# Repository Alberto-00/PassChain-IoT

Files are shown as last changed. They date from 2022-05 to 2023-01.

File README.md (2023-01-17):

<p align="center">
  
</p>
<p align="center" dir="auto">
   IoT device for password manager. 
  <br>
  A project for IoT Security<br> 
  course at University of Salerno.
</p>

<h1 dir="auto">
  <a id="user-content-project-description-and-introduction" class="anchor" aria-hidden="true" href="#project-description-and-introduction">
    <svg class="octicon octicon-link" viewBox="0 0 16 16" version="1.1" width="16" height="16" aria-hidden="true"><path fill-rule="evenodd" d="M7.775 3.275a.75.75 0 001.06 1.06l1.25-1.25a2 2 0 112.83 2.83l-2.5 2.5a2 2 0 01-2.83 0 .75.75 0 00-1.06 1.06 3.5 3.5 0 004.95 0l2.5-2.5a3.5 3.5 0 00-4.95-4.95l-1.25 1.25zm-4.69 9.64a2 2 0 010-2.83l2.5-2.5a2 2 0 012.83 0 .75.75 0 001.06-1.06 3.5 3.5 0 00-4.95 0l-2.5 2.5a3.5 3.5 0 004.95 4.95l1.25-1.25a.75.75 0 00-1.06-1.06l-1.25 1.25a2 2 0 01-2.83 0z">
      </path>
    </svg>
  </a>
  Project description and introduction
</h1>
<p dir="auto">In this section we introduce context informations for the project.</p>

<h2 dir="auto">
  <a id="user-content-introduction" class="anchor" aria-hidden="true" href="#introduction"><svg class="octicon octicon-link" viewBox="0 0 16 16" version="1.1" width="16" height="16" aria-hidden="true">
    <path fill-rule="evenodd" d="M7.775 3.275a.75.75 0 001.06 1.06l1.25-1.25a2 2 0 112.83 2.83l-2.5 2.5a2 2 0 01-2.83 0 .75.75 0 00-1.06 1.06 3.5 3.5 0 004.95 0l2.5-2.5a3.5 3.5 0 00-4.95-4.95l-1.25 1.25zm-4.69 9.64a2 2 0 010-2.83l2.5-2.5a2 2 0 012.83 0 .75.75 0 001.06-1.06 3.5 3.5 0 00-4.95 0l-2.5 2.5a3.5 3.5 0 004.95 4.95l1.25-1.25a.75.75 0 00-1.06-1.06l-1.25 1.25a2 2 0 01-2.83 0z">
    </path>
    </svg>
  </a>
  Introduction
</h2>
<p dir="auto">
    PassChain is an IoT device to store user's credentials (like username and password) and send them to other devices with a Bluetooth connection. Datas are encrypted with AES-128 bit in GCM mode and the board setup is made connecting PassChain to a server Python with a SSL communication. Each operation is authorized only if the user authenticates himself with a fingerprint.
<br>The project is produced for the IoT Security course of Master's Degree in Cybersecurity at University of Salerno.
</p>

<h1 dir="auto">
  <a id="user-content-technical-informations" class="anchor" aria-hidden="true" href="#technical-informations">
    <svg class="octicon octicon-link" viewBox="0 0 16 16" version="1.1" width="16" height="16" aria-hidden="true">
      <path fill-rule="evenodd" d="M7.775 3.275a.75.75 0 001.06 1.06l1.25-1.25a2 2 0 112.83 2.83l-2.5 2.5a2 2 0 01-2.83 0 .75.75 0 00-1.06 1.06 3.5 3.5 0 004.95 0l2.5-2.5a3.5 3.5 0 00-4.95-4.95l-1.25 1.25zm-4.69 9.64a2 2 0 010-2.83l2.5-2.5a2 2 0 012.83 0 .75.75 0 001.06-1.06 3.5 3.5 0 00-4.95 0l-2.5 2.5a3.5 3.5 0 004.95 4.95l1.25-1.25a.75.75 0 00-1.06-1.06l-1.25 1.25a2 2 0 01-2.83 0z">
      </path>
    </svg>
  </a>
  Technical informations
</h1>
<p dir="auto">In this section we introduce technical informations and installing guides!</p>

<h2 dir="auto">
  <a id="user-content-built-with" class="anchor" aria-hidden="true" href="#hardware"><svg class="octicon octicon-link" viewBox="0 0 16 16" version="1.1" width="16" height="16" aria-hidden="true">
    <path fill-rule="evenodd" d="M7.775 3.275a.75.75 0 001.06 1.06l1.25-1.25a2 2 0 112.83 2.83l-2.5 2.5a2 2 0 01-2.83 0 .75.75 0 00-1.06 1.06 3.5 3.5 0 004.95 0l2.5-2.5a3.5 3.5 0 00-4.95-4.95l-1.25 1.25zm-4.69 9.64a2 2 0 010-2.83l2.5-2.5a2 2 0 012.83 0 .75.75 0 001.06-1.06 3.5 3.5 0 00-4.95 0l-2.5 2.5a3.5 3.5 0 004.95 4.95l1.25-1.25a.75.75 0 00-1.06-1.06l-1.25 1.25a2 2 0 01-2.83 0z">
    </path>
    </svg>
  </a>
  Hardware
  </h2>
<p dir="auto">In this section we can see the circuit, in particular, how all the sensors have been connected to the Esp32 and board's datasheet.</p>
<ul dir="auto">
<li><strong>GPIO 15</strong>: metal plaque to wake up the device when it goes in deep sleep after a constant time;</li>
<li><strong>GPIO 12</strong>: battery circuit is composed of two resistence of 47K, because the board has a voltage between 2.3V - 3.6V. The line red and black are connected to the back of the board: here there is a connector that connect battery to the board;</li><br>
<li><strong>G</strong>: connection with GND (black line);</li>
<li><strong>Red line</strong>: connection with 3V;</li>
<li><strong>GPIO 26</strong>: is TX on the board (RX on fingerprint);</li>
<li><strong>GPIO 27</strong>: is RX on the board (TX on fingerprint);</li>
</ul>
<p>The blue and white line of the fingerprint are used to connect it to serial adapter but in this case we don’t need to use them.</p>
<p dir="auto"> 
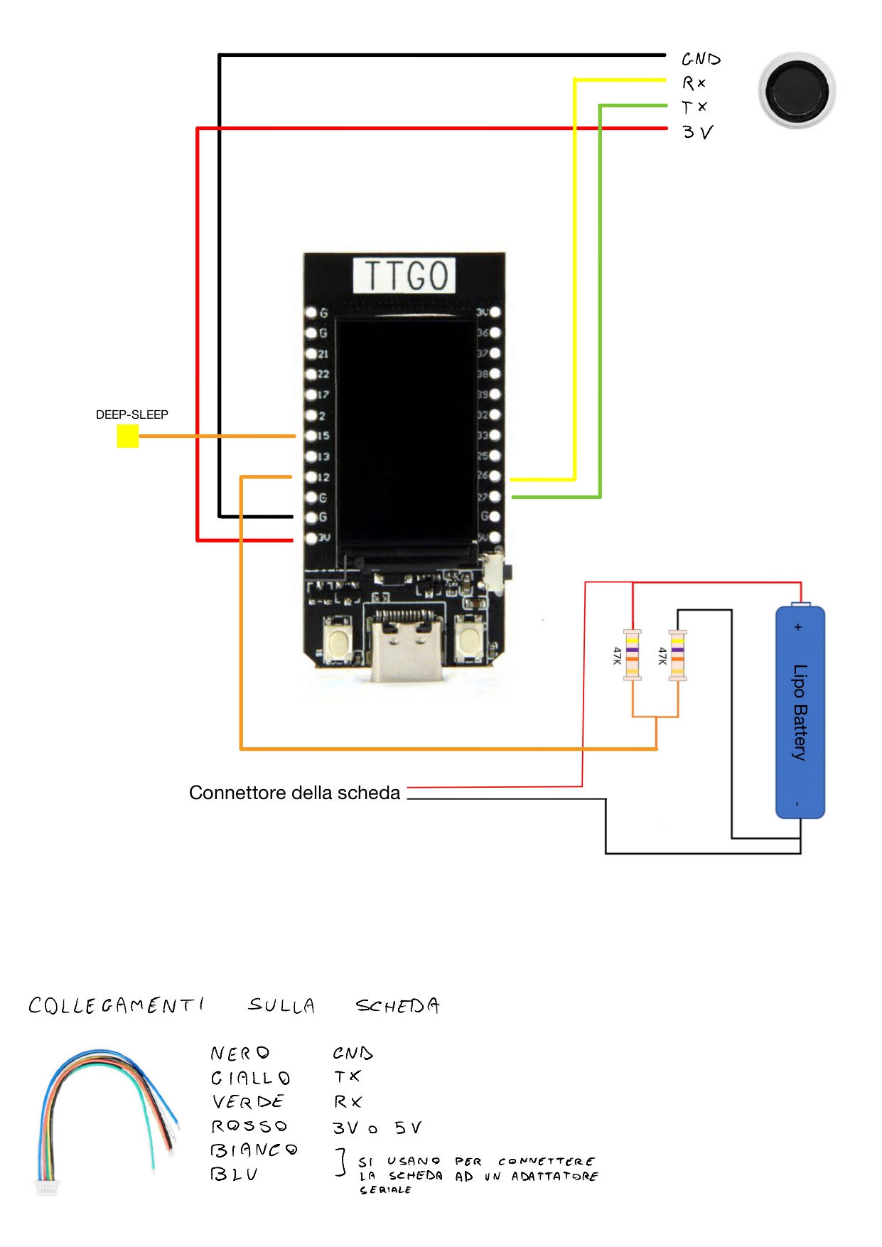
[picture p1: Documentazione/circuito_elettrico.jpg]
  
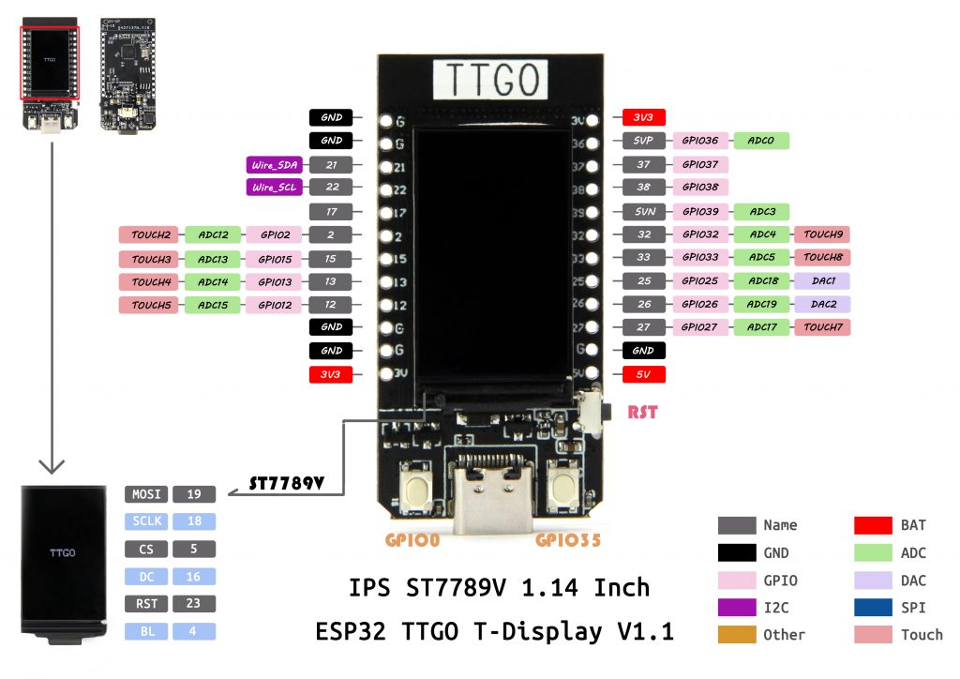
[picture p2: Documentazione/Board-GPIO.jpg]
  
</p>

<h2 dir="auto">
  <a id="user-content-built-with" class="anchor" aria-hidden="true" href="#getting-started"><svg class="octicon octicon-link" viewBox="0 0 16 16" version="1.1" width="16" height="16" aria-hidden="true">
    <path fill-rule="evenodd" d="M7.775 3.275a.75.75 0 001.06 1.06l1.25-1.25a2 2 0 112.83 2.83l-2.5 2.5a2 2 0 01-2.83 0 .75.75 0 00-1.06 1.06 3.5 3.5 0 004.95 0l2.5-2.5a3.5 3.5 0 00-4.95-4.95l-1.25 1.25zm-4.69 9.64a2 2 0 010-2.83l2.5-2.5a2 2 0 012.83 0 .75.75 0 001.06-1.06 3.5 3.5 0 00-4.95 0l-2.5 2.5a3.5 3.5 0 004.95 4.95l1.25-1.25a.75.75 0 00-1.06-1.06l-1.25 1.25a2 2 0 01-2.83 0z">
    </path>
    </svg>
  </a>
  Getting Started
  </h2>
<p dir="auto">We can see how the user does a quick login to a website using PassChain and how the board does connect to server with SSL protocol.</p>

<h3 dir="auto"><a id="user-content-first-mode" class="anchor" aria-hidden="true" href="#first-mode"><svg class="octicon octicon-link" viewBox="0 0 16 16" version="1.1" width="16" height="16" aria-hidden="true"><path fill-rule="evenodd" d="M7.775 3.275a.75.75 0 001.06 1.06l1.25-1.25a2 2 0 112.83 2.83l-2.5 2.5a2 2 0 01-2.83 0 .75.75 0 00-1.06 1.06 3.5 3.5 0 004.95 0l2.5-2.5a3.5 3.5 0 00-4.95-4.95l-1.25 1.25zm-4.69 9.64a2 2 0 010-2.83l2.5-2.5a2 2 0 012.83 0 .75.75 0 001.06-1.06 3.5 3.5 0 00-4.95 0l-2.5 2.5a3.5 3.5 0 004.95 4.95l1.25-1.25a.75.75 0 00-1.06-1.06l-1.25 1.25a2 2 0 01-2.83 0z"></path></svg></a>Send Credential</h3>


<h3 dir="auto"><a id="user-content-first-mode" class="anchor" aria-hidden="true" href="#first-mode"><svg class="octicon octicon-link" viewBox="0 0 16 16" version="1.1" width="16" height="16" aria-hidden="true"><path fill-rule="evenodd" d="M7.775 3.275a.75.75 0 001.06 1.06l1.25-1.25a2 2 0 112.83 2.83l-2.5 2.5a2 2 0 01-2.83 0 .75.75 0 00-1.06 1.06 3.5 3.5 0 004.95 0l2.5-2.5a3.5 3.5 0 00-4.95-4.95l-1.25 1.25zm-4.69 9.64a2 2 0 010-2.83l2.5-2.5a2 2 0 012.83 0 .75.75 0 001.06-1.06 3.5 3.5 0 00-4.95 0l-2.5 2.5a3.5 3.5 0 004.95 4.95l1.25-1.25a.75.75 0 00-1.06-1.06l-1.25 1.25a2 2 0 01-2.83 0z"></path></svg></a>Server Python</h3>


<h2 dir="auto">
  <a id="user-content-built-with" class="anchor" aria-hidden="true" href="#built-with"><svg class="octicon octicon-link" viewBox="0 0 16 16" version="1.1" width="16" height="16" aria-hidden="true">
    <path fill-rule="evenodd" d="M7.775 3.275a.75.75 0 001.06 1.06l1.25-1.25a2 2 0 112.83 2.83l-2.5 2.5a2 2 0 01-2.83 0 .75.75 0 00-1.06 1.06 3.5 3.5 0 004.95 0l2.5-2.5a3.5 3.5 0 00-4.95-4.95l-1.25 1.25zm-4.69 9.64a2 2 0 010-2.83l2.5-2.5a2 2 0 012.83 0 .75.75 0 001.06-1.06 3.5 3.5 0 00-4.95 0l-2.5 2.5a3.5 3.5 0 004.95 4.95l1.25-1.25a.75.75 0 00-1.06-1.06l-1.25 1.25a2 2 0 01-2.83 0z">
    </path>
    </svg>
  </a>
  Built With
  </h2>
<ul dir="auto">
  <li><a href="https://www.arduino.cc/en/software" rel="nofollow">Arduino IDE</a> - The programming language used for the board development.</li>
  <li><a href="http://www.lilygo.cn/" rel="nofollow">Lora TTgo Esp32</a> - Board used for the project.</li>
  <li><a href="https://www.adafruit.com/product/751" rel="nofollow">Adafruit Fingerprint</a> - Sensor for user authentication.</li>
  <li><a href="#" rel="nofollow">LiPo battery 500 mAh</a> - Battery of 3.7V.</li>
  <li><a href="https://github.com/Mbed-TLS/mbedtls" rel="nofollow">mbedtls/gcm</a> - Library used to encrypt and decrypt datas with AES-128 bit (GCM mode).</li>
  <li><a href="https://github.com/espressif/arduino-esp32/tree/master/libraries/WiFiClientSecure" rel="nofollow">WiFiClientSecure/gcm</a> - Library used to create and setup SSL communication.</li>
  <li><a href="https://github.com/T-vK/ESP32-BLE-Keyboard" rel="nofollow">BleKeyboard</a> - Library used to simulate a virtual keyboard.</li>
  <li><a href="https://www.openssl.org/" rel="nofollow">Openssl</a> - To generate certificates for SSL communication.</li>
  <li><a href=https://www.python.org/" rel="nofollow">Python</a> - The programming language used for server development.</li>
</ul>

<h2 dir="auto">
  <a id="user-content-authors" class="anchor" aria-hidden="true" href="#authors">
    <svg class="octicon octicon-link" viewBox="0 0 16 16" version="1.1" width="16" height="16" aria-hidden="true"><path fill-rule="evenodd" d="M7.775 3.275a.75.75 0 001.06 1.06l1.25-1.25a2 2 0 112.83 2.83l-2.5 2.5a2 2 0 01-2.83 0 .75.75 0 00-1.06 1.06 3.5 3.5 0 004.95 0l2.5-2.5a3.5 3.5 0 00-4.95-4.95l-1.25 1.25zm-4.69 9.64a2 2 0 010-2.83l2.5-2.5a2 2 0 012.83 0 .75.75 0 001.06-1.06 3.5 3.5 0 00-4.95 0l-2.5 2.5a3.5 3.5 0 004.95 4.95l1.25-1.25a.75.75 0 00-1.06-1.06l-1.25 1.25a2 2 0 01-2.83 0z">
      </path>
    </svg>
  </a>
  Author & Contacts
</h2>
<p dir="auto"><strong>Alberto Montefusco</strong>   - <em>Developer</em>   - <a href="https://github.com/Alberto-00">Alberto-00</a></p>
<p dir="auto">Email - <a href="mailto:a.montefusco28@studenti.unisa.it">a.montefusco28@studenti.unisa.it</a></p>
<p dir="auto">LinkedIn - <a href="https://www.linkedin.com/in/alberto-montefusco">Alberto Montefusco</a></p>
<p dir="auto">My WebSite - <a href="https://alberto-00.github.io/">alberto-00.github.io</a></p>

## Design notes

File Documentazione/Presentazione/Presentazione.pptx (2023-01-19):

## void PassChain_IoT() {

PassChain.ino

Details.ino

/* Presentazione di Alberto Montefusco */

const char *corso = ‘IoT Security’;

}

const char *Prof = ‘Christiancarmine Esposito’;

const char *aa = ‘2022 - 2023’;

Presentation.begin(course, Prof, aa);

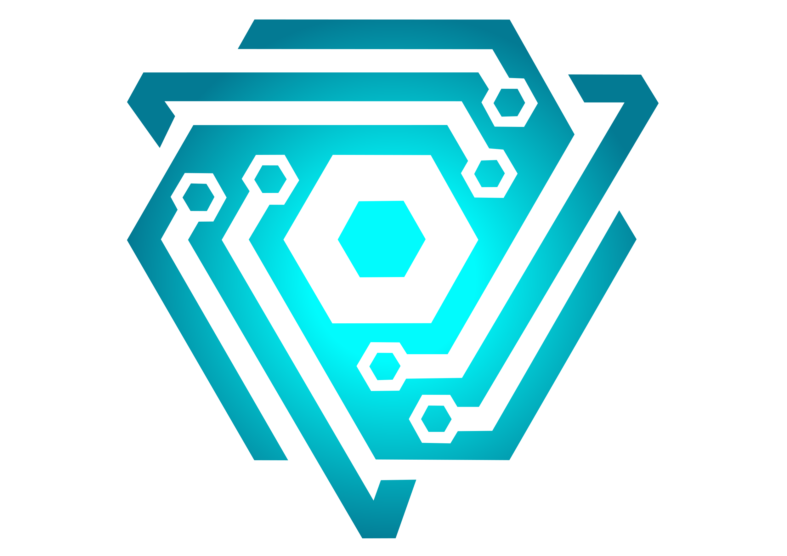
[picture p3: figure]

Arduino Language

## 01 02 03 Table Of ‘Contents’ {

PassChain.ino

Details.ino

}

Introduzione

/* Introduzione ai Password Manager e a PassChain */

Hardware

/* Sensori usati e descrizione del circuito finale */

Software

/* Librerie usate, comunicazione SSL, server Python */

04

Vulnerabilità_&_Sicurezza

/* Attacchi e Soluzioni Sicure */

Arduino Language

## 01 { [Introduzione]

PassChain.ino

Details.ino

/* Cos’è un PassWord Manager
e il dispositivo PassChain */

}

Arduino Language

## Password_Manager {

PassChain.ino

/* Cosa sono? */

Details.ino

}

Serial.println(‘Servizi online che permettono all’utente di salvare password’);
delay(100);

Serial.println(‘ e sincronizzarle su tutti i dispositivi personali’);

Arduino Language

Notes: Permettono, quindi, un’archiviazione sicura e cifrata mediante l’utilizzo di una Master Password, che serve per accedere al password manager.

## tft.pushImage (

PassChain.ino

Details.ino

Dashlane e 1Password sono i Password Manager più famosi

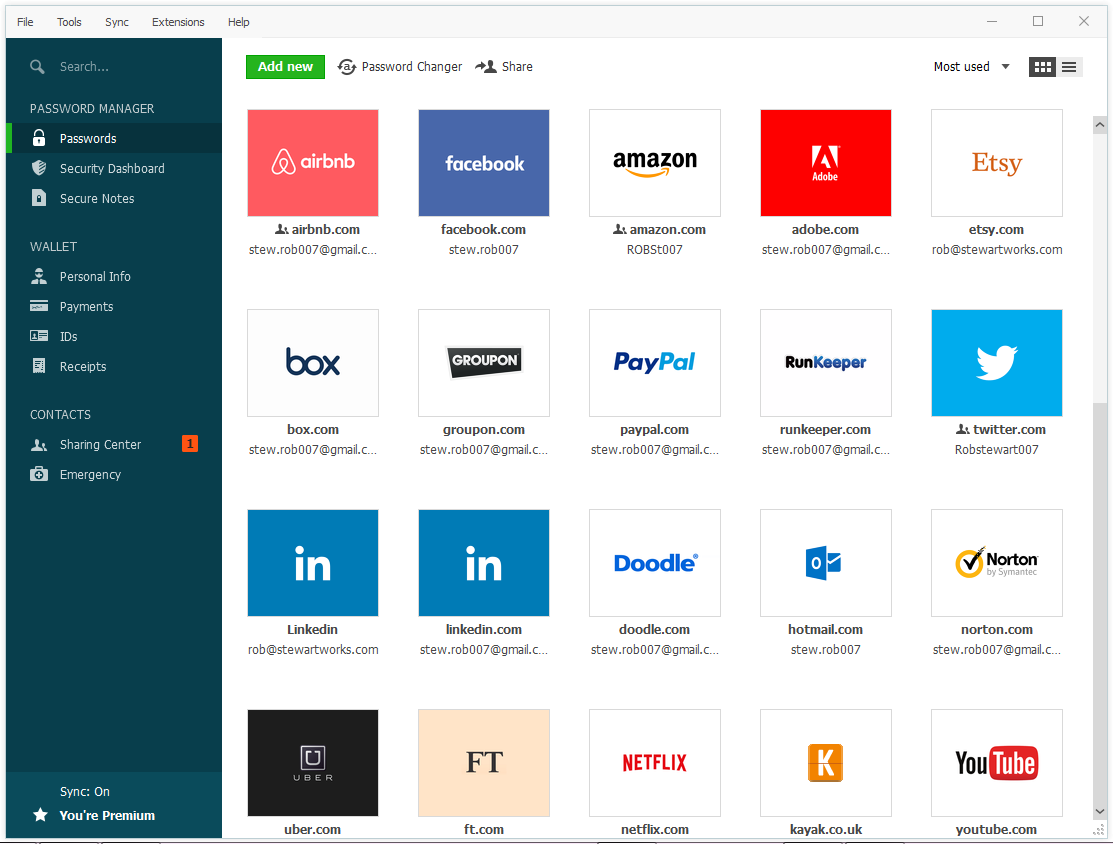
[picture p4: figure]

);

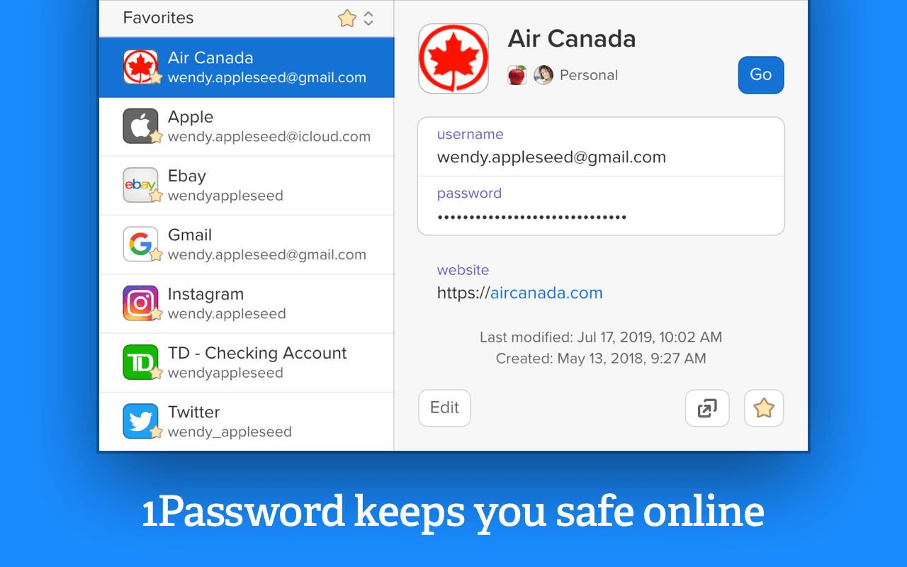
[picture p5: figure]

Arduino Language

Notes: Tra I password manager più famosi abbiamo Dashline e 1Password

## Serial.println (‘Vantaggi: ‘ +

PassChain.ino

Details.ino

Step 01

Le App sono disponibili per tutte le piattaforme

Step 02

Alcune estensioni Browser permettono di inserire le password automaticamente

Step 03

Le password sono sincronizzate su tutti i dispositivi

Step 04

Accesso veloce

);

Arduino Language

## Serial.println (‘Svantaggi: ‘ +

PassChain.ino

Details.ino

Step 01

I servizi online e cloud possono essere violati anche da remoto

Step 02

Installare un'applicazione o un'estensione su ciascuno dei propri dispositivi personali

Step 03

Meno pratico quando si usano dispositivi non personali

Sigle Point of Failure perché l'accesso a tutte le tue password è protetto da un'unica password sicura

Step 04

);

Arduino Language

## PassChain_IoT {

PassChain.ino

/* Cos’è PassChain? */

Serial.println(‘PassChain è un dispositivo IoT con l’obbietivo di facilitare l'utente durante l’autenticazione digitale’);
delay(100);
Serial.println(‘ma anche di garantire la loro sicurezza attraverso la sua funzione di password manager’);

Details.ino

}

Bluetooth

< Connessione ad altri dispositivi tramite Bluetooth >

Autenticazione

< Ogni operazione è compiuta tramite autenticazione con Fingerprint >

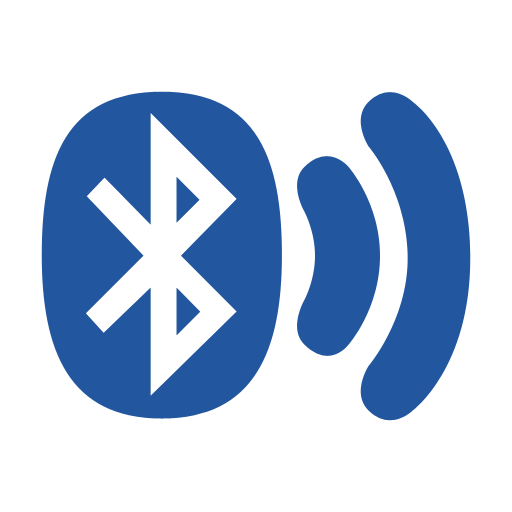
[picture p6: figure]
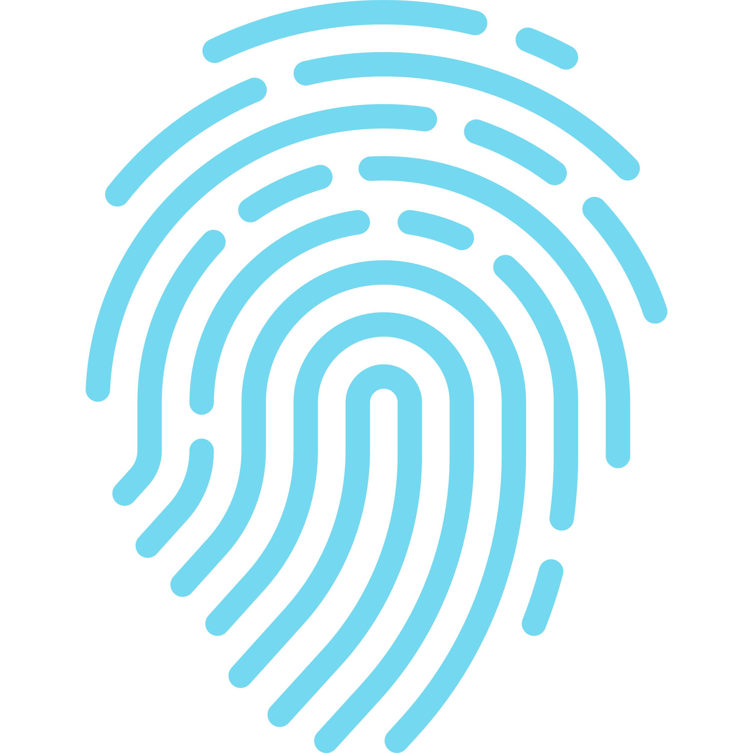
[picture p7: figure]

Crittografia

< Tutti i dati sono cifrati con lo schema AES 128 bit – GCM >

Comunicazione SSL

< SSL garantisce una comunicazione sicura con il server python >

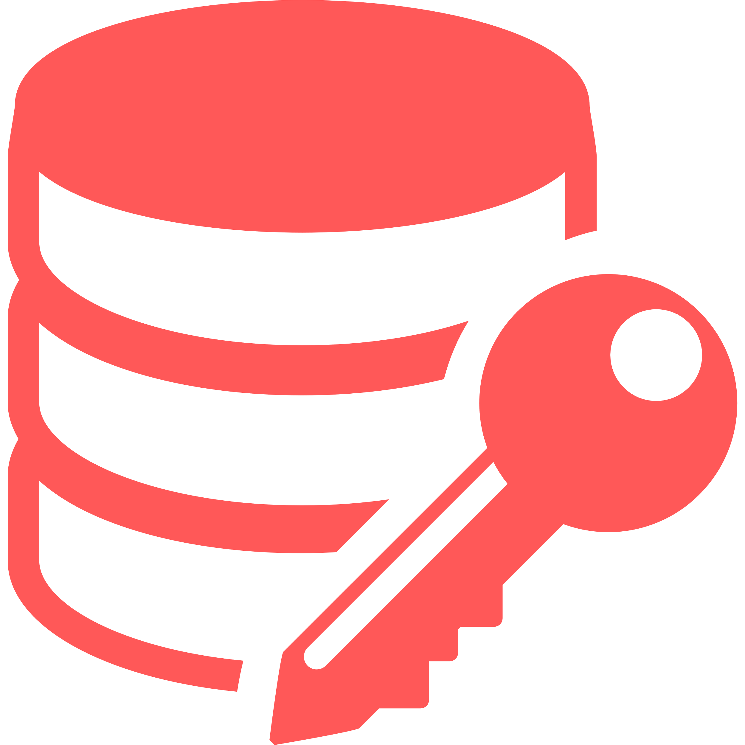
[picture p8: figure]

Arduino Language

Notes: PassChain è un dispositivo IoT con l’obbietivo di facilitare l'utente durante l’autenticazione digitale permettendogli di inviare le credenziali a qualsiasi dispositivo che supporta una connessione Bluetooth. Inoltre, garantisce anche una forte sicurezza grazie alla sua funzione di password manager, infatti, tutti i dati all’interno sono cifrati.

## SD_Send_Credential {

PassChain.ino

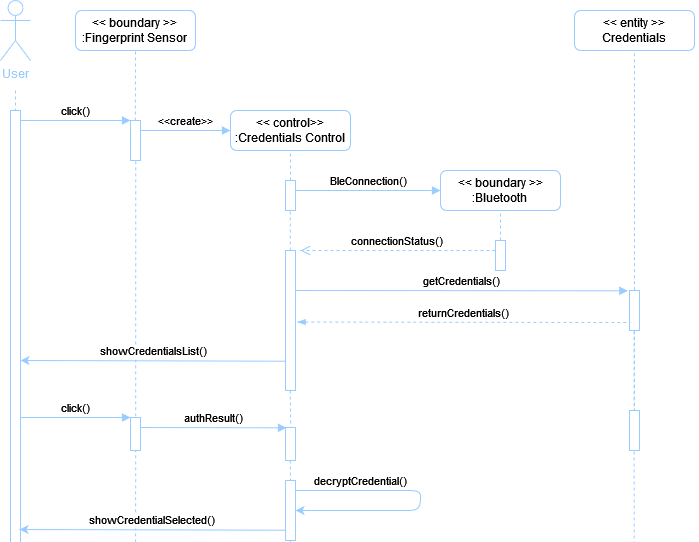
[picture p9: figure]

Arduino Language

Details.ino

}

## SD_Send_Credential {

PassChain.ino

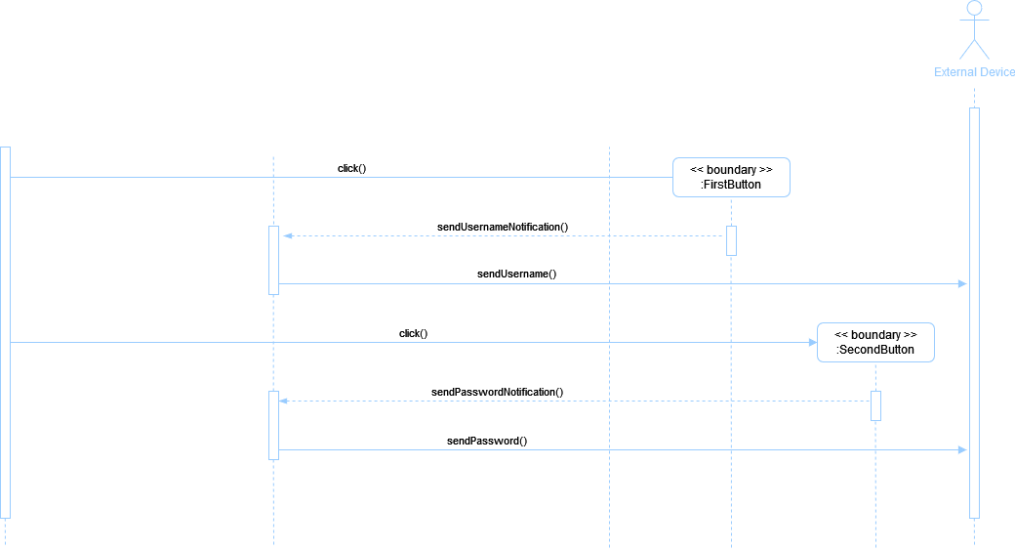
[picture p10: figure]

Details.ino

}

Arduino Language

## SD_Server_Operation {

PassChain.ino

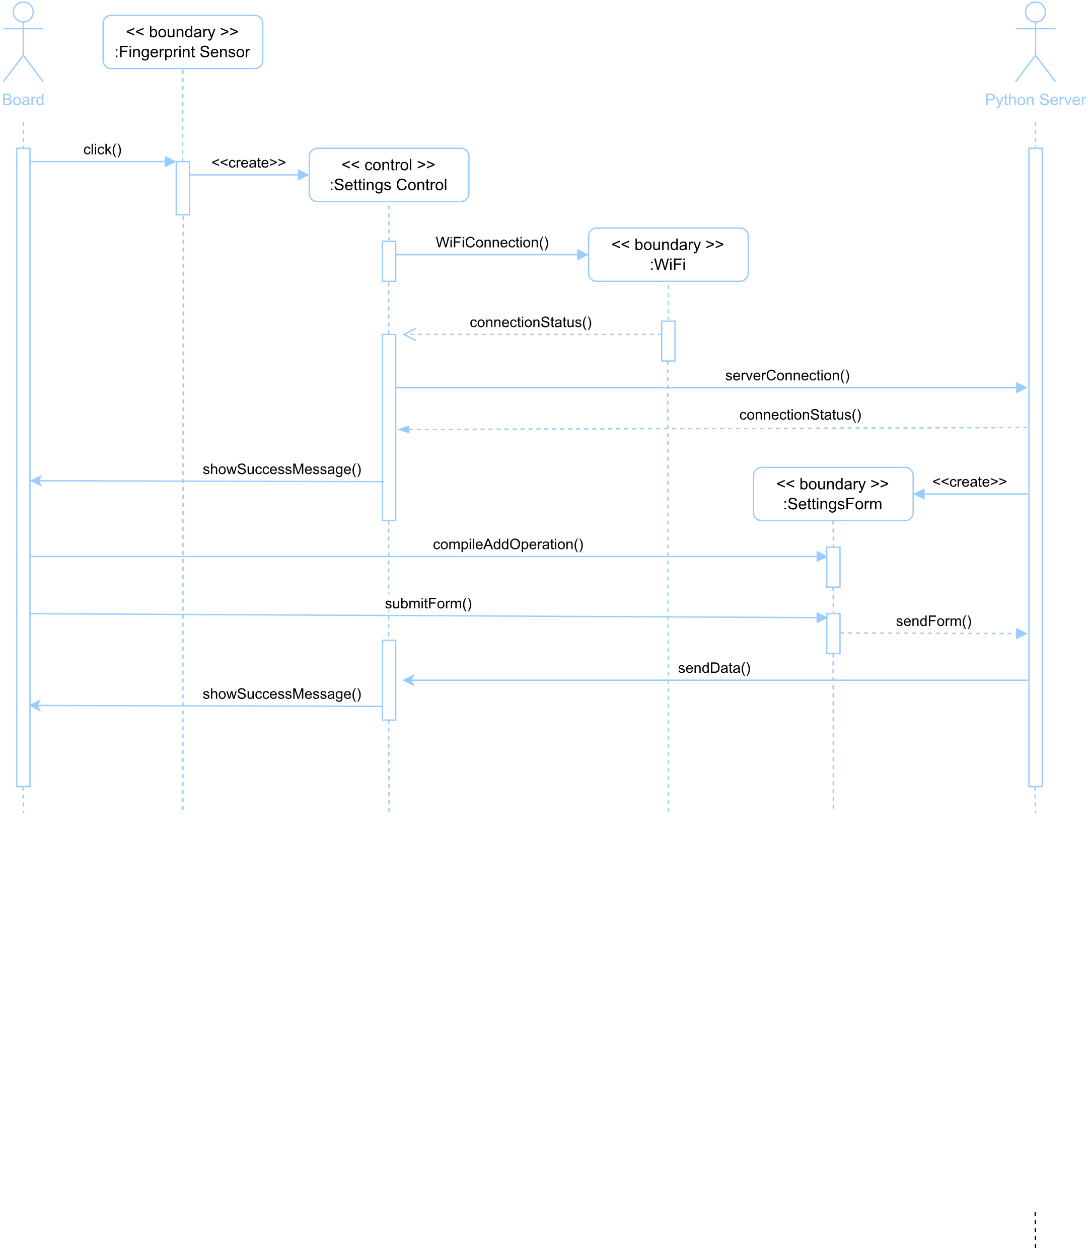
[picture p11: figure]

Arduino Language

Details.ino

}

## 02 { [Hardware]

PassChain.ino

Details.ino

/* Lora TTgo Esp32 16 Mb,
Fingerprint, Battery */

}

Arduino Language

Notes: Now we can see the Hardware used

## void Lora_TTgo_Esp32 () {

PassChain.ino

< La scheda ha un display OLED integrato da 0,96'', due pulsanti programmabili e uno per il riavvio, un connettore di alimentazione per le batterie e una porta di tipo C per il collegamento del dispositivo e l'alimentazione della scheda stessa. Ha una memoria di 16 Mb con SPIFFS come file system >

Details.ino

}

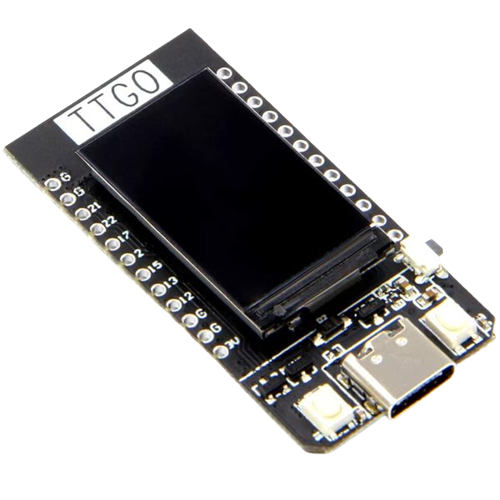
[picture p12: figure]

void Fingerprint () {

< Il sensore di impronte digitali consente di autenticare l'utente garantendone l'unicità. Il sensore può memorizzare 126 impronte digitali: una di queste serve per tornare indietro nelle impostazioni >

}

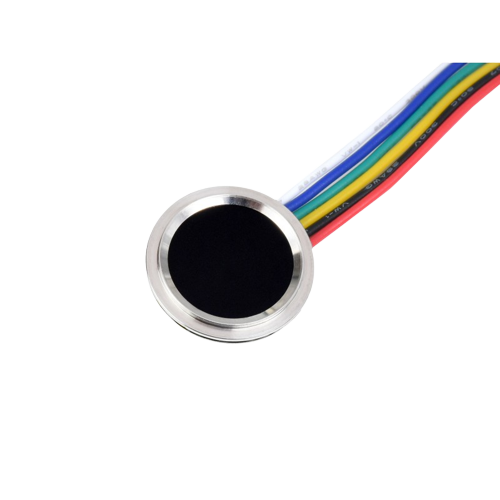
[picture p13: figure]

Arduino Language

## void Lora_Ttgo_Esp32 () {

PassChain.ino

< La batteria LiPo da 500 mAh e 3,7 V consente di avere un dispositivo portatile e indipendente >

Details.ino

}

void show_circuit (Board esp32, Sensor fingerprint, Sensor battery) {

Circuit circuit = new Circuit (Esp32, fingerprint, battery);

}

tft.pushImage(circuit.show());

Arduino Language

## tft.pushImage (

PassChain.ino

Details.ino

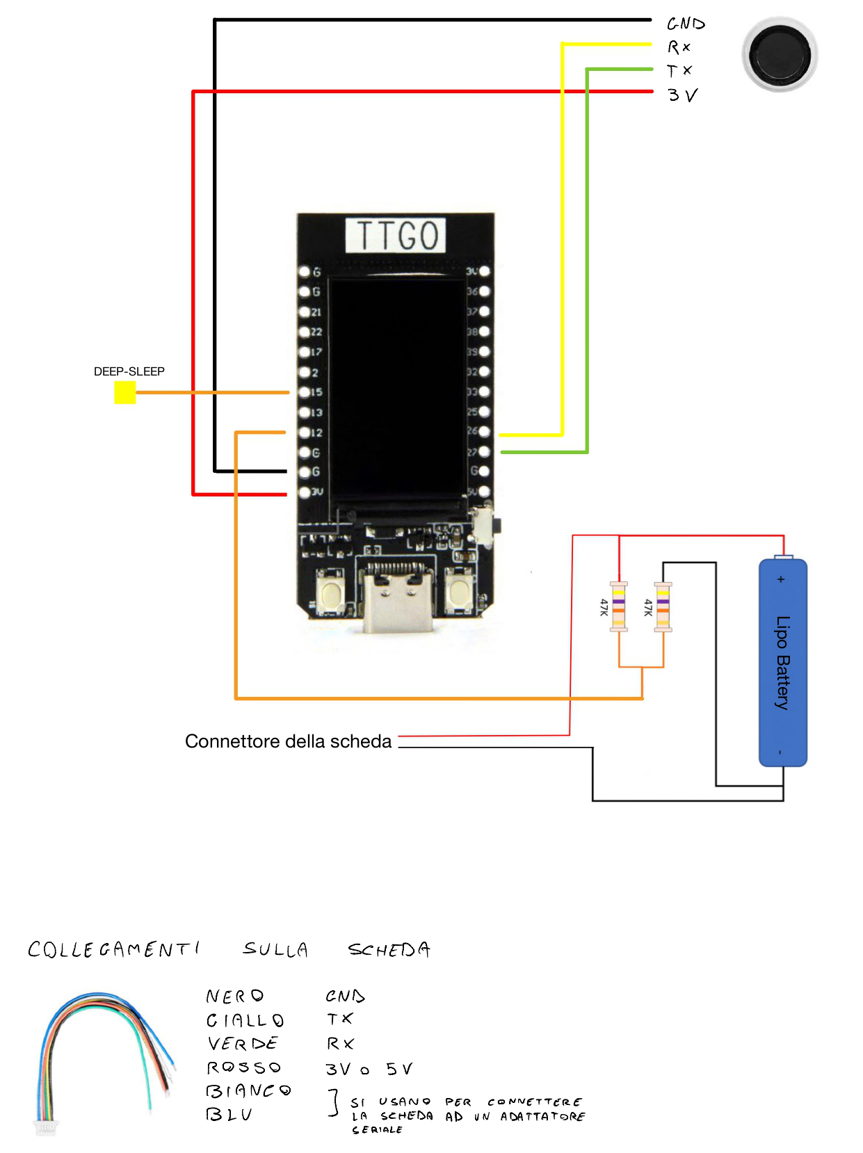
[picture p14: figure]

- GPIO 15: placca metallica per riattivare la board quando entra in modalità deep_sleep
- GPIO 12: circuito della batteria

);

Arduino Language

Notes: Sul GPIO 15 è collegata una placca metallica per riattivare il dispositivo quando entra in modalità deep sleep dopo un certo intervallo di tempo.

Sul GPIO 12 è collegata la batteria, in particolare il circuito è composto da due resistenze da 47K, in quanto la scheda ha una tensione compresa tra 2.3V - 3.6V. Le linee rossa e nera sono collegate al retro della scheda: qui c'è un connettore che collega la batteria alla scheda

## tft.pushImage (

PassChain.ino

Details.ino

- G: connnessione con GND
- La line rossa è collegata alla 3V
- GPIO 26: TX della scheda
- GPIO 27: RX della scheda

);

Arduino Language

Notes: Ora vediamo il collegamento del sensore del fingerprint:
G è la connessione con GND (linea nera);
la linea rossa è la connessione con 3V;
GPIO 26 (linea gialla) è TX sulla scheda (RX sul dito);
GPIO 27 (linea verde) è RX sulla scheda (TX sul dito);
La linea blu e bianca dell'impronta digitale servono per collegarla ad un’adattatore seriale ma in questo caso non vengono utilizzate.

## 03 { [Software]

PassChain.ino

Details.ino

/* Librerie usate, comunicazione SSL,
server Python */

}

Arduino Language

## Libraries_used(bool external) { < TFT_eSPI.h > < SD.h >

PassChain.ino

Details.ino

if (!external) { /* dettagli librerie Arduino */

- Libreria Arduino usata per scrivere
- testo o visualizzare immagini sul
- display OLED.

- Libreria Arduino per leggere e scrivere
- in memoria. Il file system usato è
- SPIFFS.

Libreria Arduino usata per gestire i
file JSON, nei quali sono memorizzate
le credenziali utente e dell’Hotspot

< ArduinoJson.h >

Arduino Language

## < WiFiClientSecure.h > < BleKeyboard.h >

PassChain.ino

< mbedtls/gcm.h >

Details.ino

- Libreria Arduino usata per creare e
- fare il setup della comunicazione SSL

Cifratura e decifratura dei dati con lo
schema AES - 128 bit GCM mode

} else { /* dettagli delle librerie esterne */

- Simulare una tastiera virtuale e
- inviare i messaggi tramite Bluetooth

Gestione delle impronte digitali

}

< Adafruit_Fingerprint.h >

}

Arduino Language

## SSL_Communication {

PassChain.ino

Details.ino

/***********************************************************************
* Ho creato una comunicazione sicura tra l’Esp32 e il dispositivo *
* esterno che funge da server per fare il setup dei dati. *
***********************************************************************/

}

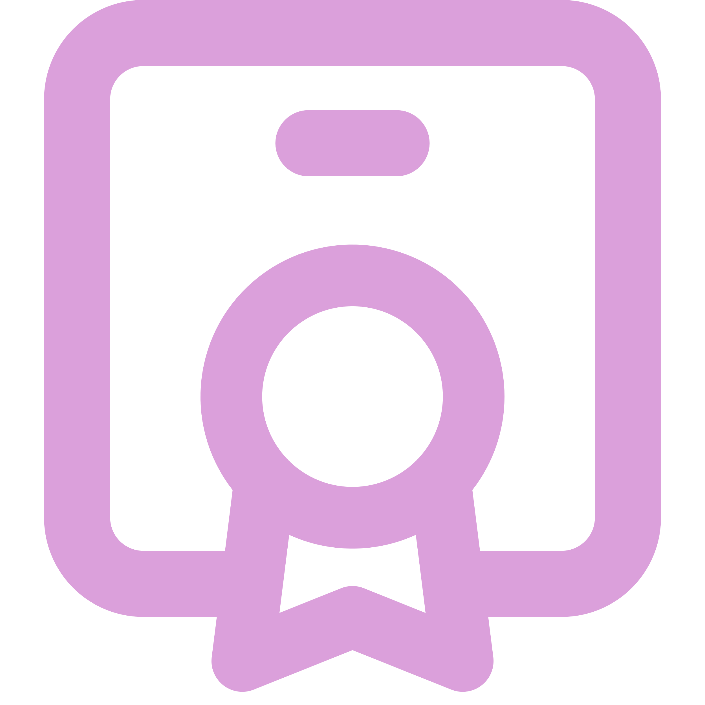
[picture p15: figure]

Creazione Certificati

< Certificati CA, client e chiave associata del client >

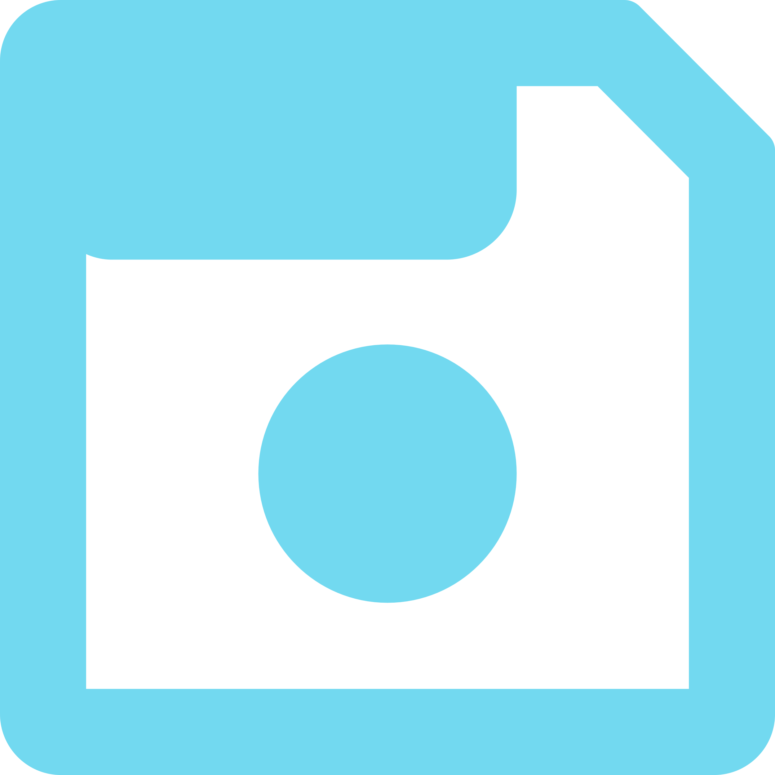
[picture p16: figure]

Salvataggio Certificati

< I certificati sono salvati nel codice Arduino e inviati al server >

Start Server Python

< Caricamento del certificato del server e verifica di esso e del certificato client >

Recezione dati

< Il server crea una socket e riceve i dati dall’ESP32 >

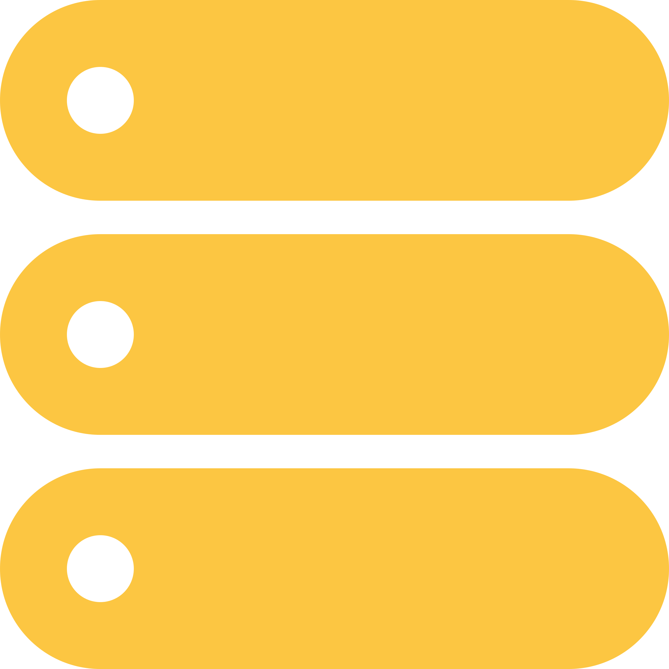
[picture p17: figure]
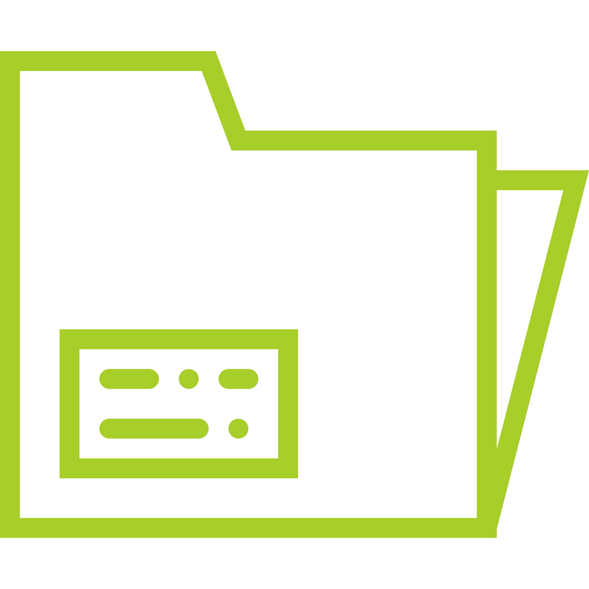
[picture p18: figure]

Arduino Language

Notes: La comunicazione SSL consente una comunicazione sicura tra due dispositivi. In questo caso, creo una comunicazione sicura tra l’Esp32 e il dispositivo esterno che funge da server per fare il setup dei dati.

I primi passi sono la creazione dei certificati CA, client e server con le relative chiavi (io ho usato openssl, in particolare rsa 2048 bit);
Il secondo passo è memorizzare il CA, client e la sua chiave nel codice Arduino e quindi inviare il certificato client al server per verificarlo.
Il server python carica il certificato del server e lo verifica.
Il server crea una socket su una porta specifica e si prepara a ricevere dati da Esp32.

## Server_Python {

PassChain.ino

Details.ino

/***********************************************************************
* Permette di effettuare il setup della scheda. Le operazioni *
* riguardano: aggiunta, modifica ed eliminazione delle credenziali, *
* setup del fingerprint, setup credenziali dell'hotspot *
***********************************************************************/

}

Start server

< Stringa di benvenuto, numero di fingerprint, JSON con le credenziali >

Operazioni CRUD

< Per il setup Esp32, possiamo eseguire operazioni CRUD sui dati >

Setup Fingerprints

< Il Server verifica se ci
sono almeno 2 FP:
- conferma delle operazioni
- tasto per tornare indietro >

Arduino Language

Setup Hotspot

< Il Server può modificare l’SSID e la password dell’hotspot >

## 04 { [Vulnerabilità & Sicurezza]

PassChain.ino

Details.ino

/* Attacchi e
Soluzioni Sicure */

}

Arduino Language

## void MITM_attack (Adv, Alice, Bob) {

PassChain.ino

PassChain.ino

Details.ino

Details.ino

/*********************************************************************
* PassChain è vulnerabile all'attacco MITM su Bluetooth perché *
* manca l'autenticazione tra i due dispositivi. Una soluzione è *
* utilizzare BLE v4.2 BR/EDR utilizzando la crittografia basata su *
* ECDH e utilizzando il modello di binding di confronto numerico *
* per l'autenticazione *
*********************************************************************/
< Questa soluzione non è forte perchè la v4.2 fino alla 5.0 soffrono di una vulnerabilità chiamata "BLURtooth" che sfrutta il CTDK >

< Questo debolezza è stata risolta dal
Protocollo GATT, disponibile nelle ultime
versioni dei dispositivi dotati di BLE >

Arduino Language

}

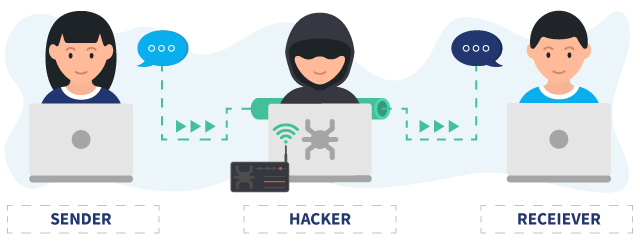
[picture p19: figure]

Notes: Questa soluzione non è forte perché dalla v4.2 a 5.0 hanno una vulnerabilità chiamata "BLURtooth" che sfrutta CTDK (Cross-Transport Key Derivation). Questo componente gestisce due diversi set di chiavi di autenticazione per garantire che le relative chiavi siano sempre pronte all'uso, delegando i dispositivi a decidere in fase di pairing quale versione dello standard utilizzare con il rispettivo gruppo di chiavi. L'attacco compromette il processo CTKD sovrascrivendo le chiavi di autenticazione o declassandole ad un livello inferiore per sfruttare un protocollo di crittografia meno robusto.

## void Exploit_FP (memory) {

PassChain.ino

PassChain.ino

Details.ino

Details.ino

}

/*******************************************************************
* PassChain usa il Fingerprint per autenticare l’utente quando *
* esegue un’operazione. *
*******************************************************************/
< La vulnerabilità consiste nello sfruttare la comunicazione UART perchè il sensore usa il Seriale TTL per comunicare. Ad esempio, possiamo usare Attify Badge per emulare una connessione seriale ed accedere al dispositivo target >

< Una soluzione è di isolare PassChain da questi
dispositivi, in particolare, l’utente non deve lasciare
incustodita la board >

Arduino Language

## void DoS_attack (resources) {

PassChain.ino

PassChain.ino

Details.ino

Details.ino

/*******************************************************************
* L’utente può eseguire il setup di PassChain connettendo il *
* dispositivo al server Python. *
*******************************************************************/
< Un malintenzionato può eseguire un attacco DoS esaurendo le risorse dell’host che sta eseguendo il server e interrompendo i servizi dell’host connesso alla rete >

}

< In questo modo l’utente non
può connettersi al server ed
eseguire il setup della scheda >

Arduino Language

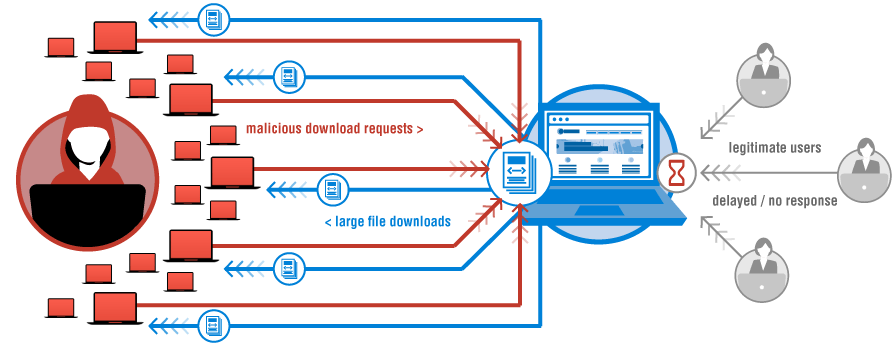
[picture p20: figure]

## void Security_Solution (crypto, SSL) { Tag AES_128 (plainText, key, IV); void SSL (certs);

PassChain.ino

Details.ino

< Le soluzioni sicure adottate sono l’uso della crittografia e della cominicazione SSL >

- I dati sono salvati sul dispositivo
- cifrati usando lo schema AES-128 bit con
- la modalità GCM

- I dati sono inviati dal server Python
- all’Esp32 in chiaro perchè la
- comunicazione è realizzata con SSL
- garantendo autenticazione, integrità e
- riservatezza

}

Arduino Language

## Tag AES_128 (plainText, key, IV) {

PassChain.ino

/*********************************************************************
* AES-GCM è un cifrario a blocchi che garantisce autenticazione, *
* confidenzialità e integrità. *
*********************************************************************/
< Abbiamo 4 input:
- Secret key (128-bit);
- IV (96-bit);
- Plaintext;
- Optional addition authenticated data (AAD) >

Details.ino

}

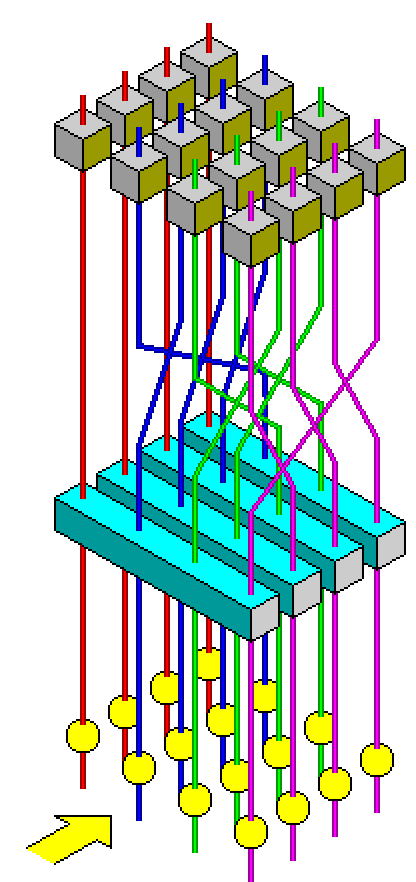
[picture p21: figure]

Arduino Language

## Tag AES_128 (plainText, key, IV) {

PassChain.ino

/**********************************************************************
* La chiave deve essere generate casualmente, ad esempio utilizzando *
* le response PUF in Esp32. *
**********************************************************************/
< Ciò è utile perché un PUF viene utilizzato per creare chiavi che vengono generate su richiesta e cancellate una volta utilizzate. La chiave PUF non esiste in forma digitale all'interno del circuito integrato ed è derivata e prodotta su richiesta sfruttando le caratteristiche intrinsiche degli elementi del circuito >

< Nel nostro caso abbiamo una chiave di test
salvata hard-coded nel codice Arduino >

Details.ino

}

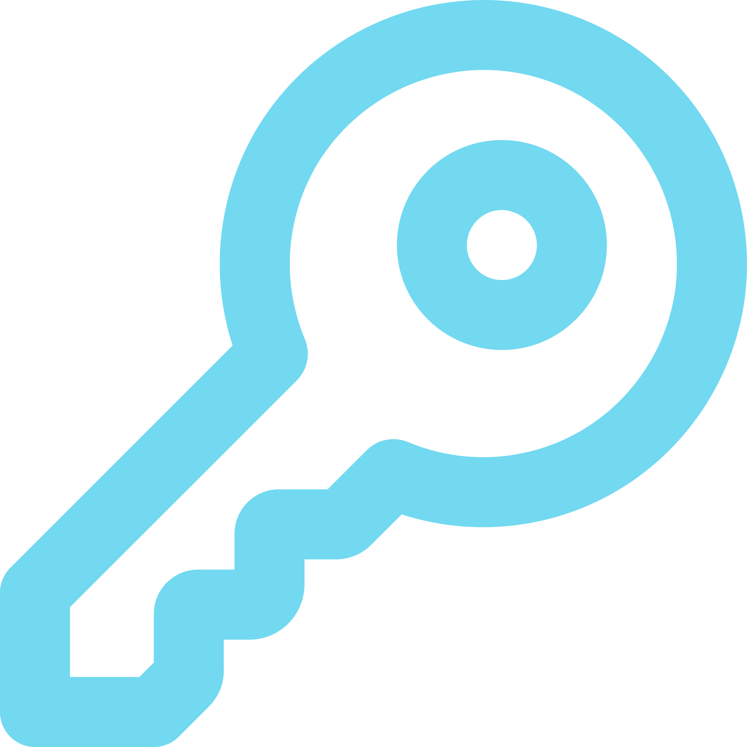
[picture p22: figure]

Arduino Language

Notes: Qualsiasi tentativo di scoprire la chiave PUF tramite micro-sondaggio o altre tecniche invasive interromperà i circuiti utilizzati per costruire la chiave PUF e renderà inutile l'output.

## Tag AES_128 (plainText, key, IV) {

PassChain.ino

/******************************************************************
* Gli IV sono generati randomicamente sfruttando RGN Hardware *
* dell’Esp32. *
******************************************************************/
< La funzione esp_random() produce dei TRN solo se il Wi-Fi o il Bluetooth sono attivi. La funzione ritorna un intero di 32 bit, in questo modo la stringa IV è costruita in append generando altri TRN per produrre in output una stringa di 96 bit >

< Ogni credenziale ha il suo IV salvato in chiaro
e l’IV associato cambia ad ogni cifratura della
stessa credenziale >

Details.ino

}

IV

Arduino Language

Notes:
L'AAD non viene utilizzato ma confronto il TAG di cifratura con il TAG di decifratura per verificare che l'intera stringa sia cifrata senza troncamenti.

## Serial.println (‘Vantaggi AES: ‘ +

PassChain.ino

Details.ino

Step 01

Algoritmo veloce

Step 02

La chiave può essere lunga 128 – 192 – 296 bit non permettendo attacchi di brute force

Step 03

La taglia di ogni blocco è di 128 bit

Step 04

La modalità GCM garantisce autenticazione, riservatezza e integrità

);

Arduino Language

## Serial.println (‘Svantaggi AES: ‘ +

PassChain.ino

Details.ino

Step 01

Se il nonce viene riutilizzato le proprietà di riservatezza e integrità saranno violate

Step 02

Tag corti producono messaggi fasulli

Step 03

Le implementazioni GCM sono vulnerabili ai timing attacks

Step 04

GCM è vulnerabile ai cycling attacks

);

Arduino Language

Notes: Se lo stesso nonce viene utilizzato due volte, un avversario può facilmente creare testi cifrati contraffatti.

I tag brevi producono messaggi contraffatti. Ad esempio, se il tag è di 32 bit, dopo 2^16 tentativi di contraffazione e 2^16 crittografie di testi in chiaro scelti, è possibile produrre un testo cifrato contraffatto.

Le implementazioni GCM sono vulnerabili agli attacchi di temporizzazione se non utilizzano istruzioni AES speciali. La vulnerabilità rimane anche se l'AES stesso è implementato in tempo costante. Esistono implementazioni a tempo costante di GCM, ma sono piuttosto lente.

## void SSL (certs) {

PassChain.ino

/*************************************************************************
* SSL è stato utilizzato per creare un canale sicuro durante lo scambio *
* di dati tra il server Python e la scheda. *
************************************************************************/
< SSL ci permette di autenticare PassChain utilizzando dei certificati. Prima che avvenga lo scambio di dati, il server controlla i certificati client e server >

< SSL è un protocollo pesante a causa della continua
cifratura e decifratura dei dati quando partono e
arrivano a destinazione e bisogna generare nuovi
certificati per ogni nuova scheda che si connette al
server >

Arduino Language

PassChain.ino

Details.ino

Details.ino

}

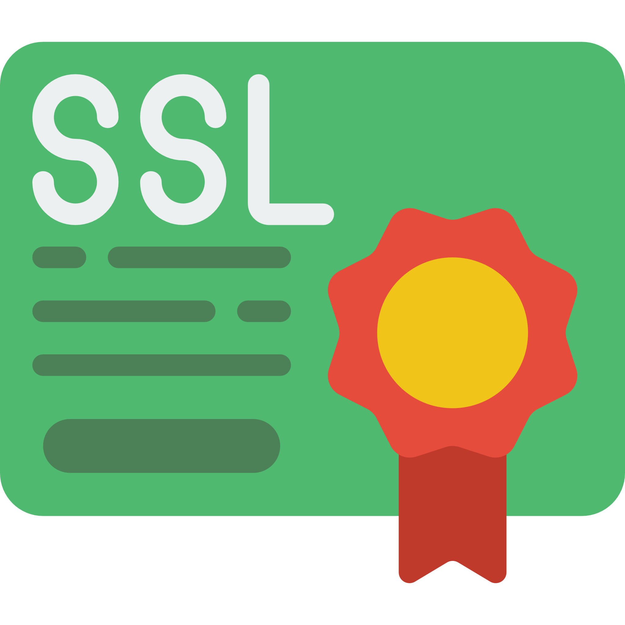
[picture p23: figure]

## Serial.println (‘Vantaggi SSL: ‘ +

PassChain.ino

Details.ino

Il client utilizza la chiave pubblica del server per cifrare i dati; il server utilizza la chiave pubblica nel certificato client per decifrare i dati inviati dal client

Autenticazione

Integrità

SSL fornisce l'integrità dei dati calcolando un digest del messaggio

SSL utilizza una combinazione di crittografia simmetrica e asimmetrica per garantire la riservatezza dei messaggi

Riservatezza

);

Arduino Language

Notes: Autenticazione: per l'autenticazione del server, il client utilizza la chiave pubblica del server per crittografare i dati. Il server può generare la chiave segreta solo se può decifrare quei dati con la chiave privata corretta. Per l'autenticazione client, il server utilizza la chiave pubblica nel certificato client per decrittografare i dati inviati dal client durante il passaggio 5 dell'handshake. Lo scambio di messaggi finiti conferma che l'autenticazione è completa. Se uno qualsiasi dei passaggi di autenticazione fallisce, l'handshake fallisce e la sessione termina.

Riservatezza: SSL utilizza una combinazione di crittografia simmetrica e asimmetrica per garantire la privacy dei messaggi. Durante l'handshake SSL, il client e il server SSL concordano un algoritmo di crittografia e una chiave segreta condivisa da utilizzare solo per una sessione. Tutti i messaggi trasmessi tra il client e il server SSL vengono crittografati utilizzando tale algoritmo e chiave, garantendo che il messaggio rimanga privato anche se viene intercettato.

## void ringraziamenti () { Serial.println(‘Grazie ’); Serial.println(‘per l’attenzione’);

PassChain.ino

Details.ino

}

Arduino Language

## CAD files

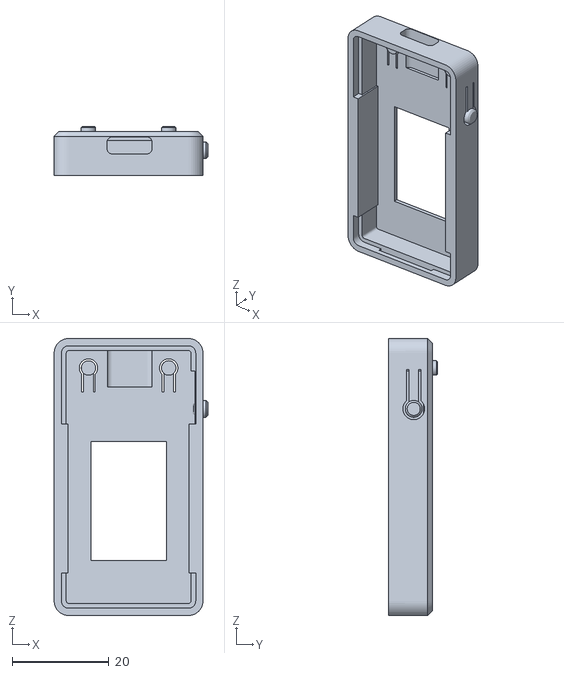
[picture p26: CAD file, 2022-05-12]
memory flash/TTGO-T-Display-master/3d_file/prt0005_14(2).stl
31.8 x 10.1 x 57.3

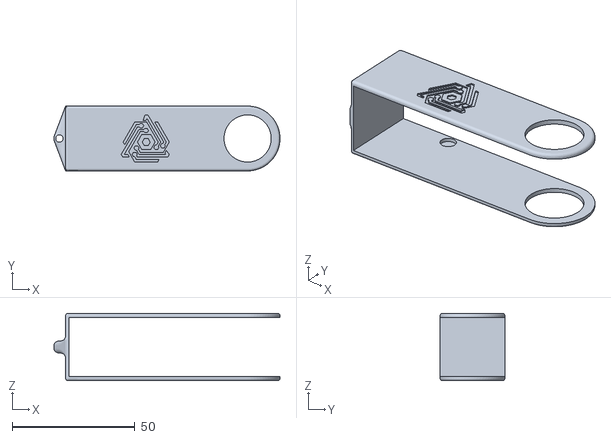
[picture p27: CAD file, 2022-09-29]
PassChain_Design 3D/Sliding_cover.stl
92.0 x 26.4 x 27.4

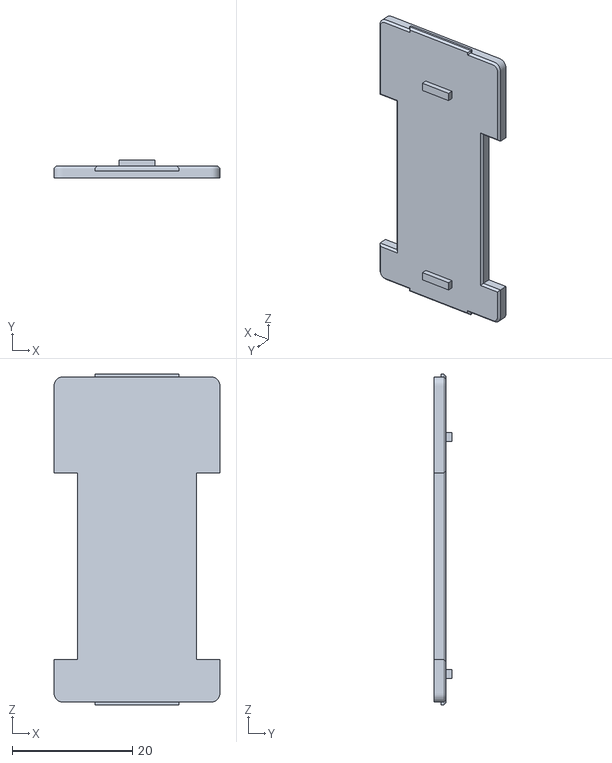
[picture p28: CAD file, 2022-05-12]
memory flash/TTGO-T-Display-master/3d_file/prt0003_23.stl
27.6 x 3.00 x 55.1

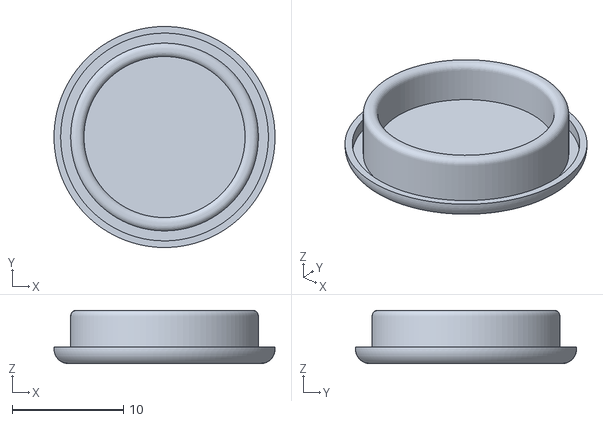
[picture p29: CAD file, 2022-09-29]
PassChain_Design 3D/Rotate_cap.stl
19.9 x 19.9 x 4.80

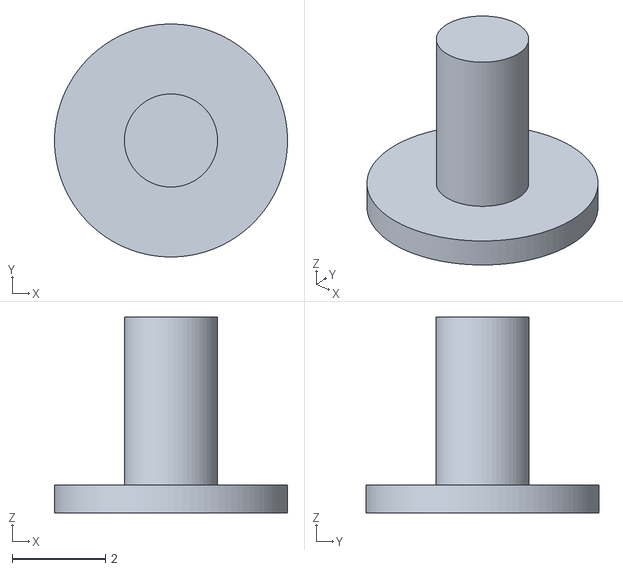
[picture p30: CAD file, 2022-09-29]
PassChain_Design 3D/Button.stl
5.00 x 5.00 x 4.20

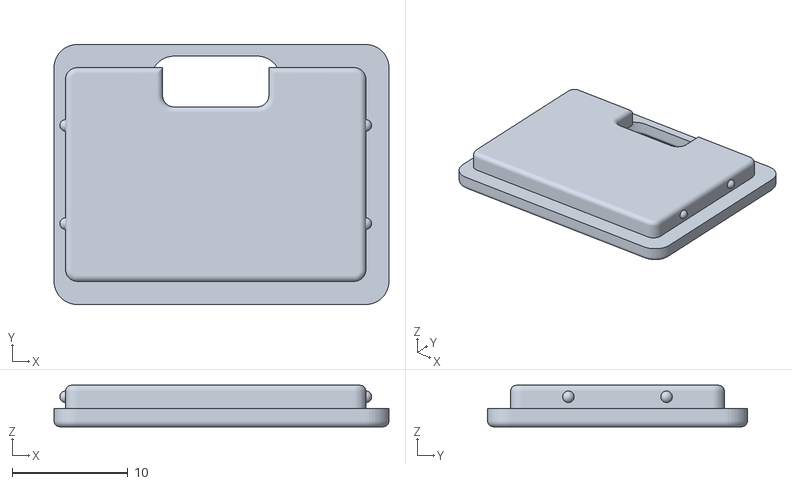
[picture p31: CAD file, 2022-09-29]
PassChain_Design 3D/Enclosure_cap.stl
29.0 x 22.5 x 3.60

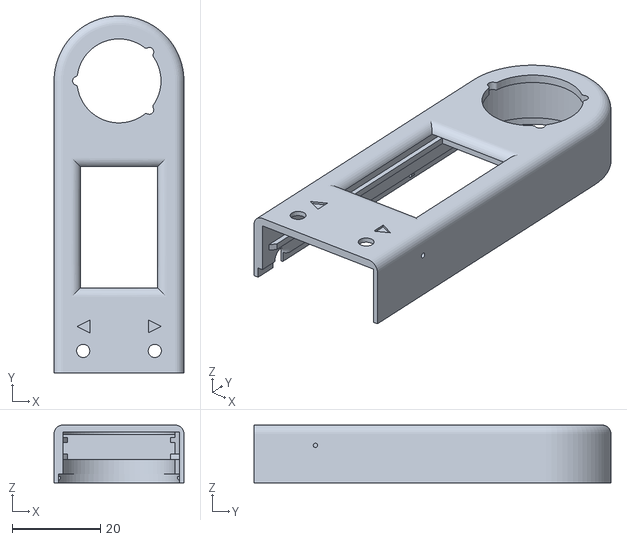
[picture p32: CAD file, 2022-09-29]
PassChain_Design 3D/Enclosure-top.stl
29.4 x 80.8 x 13.1

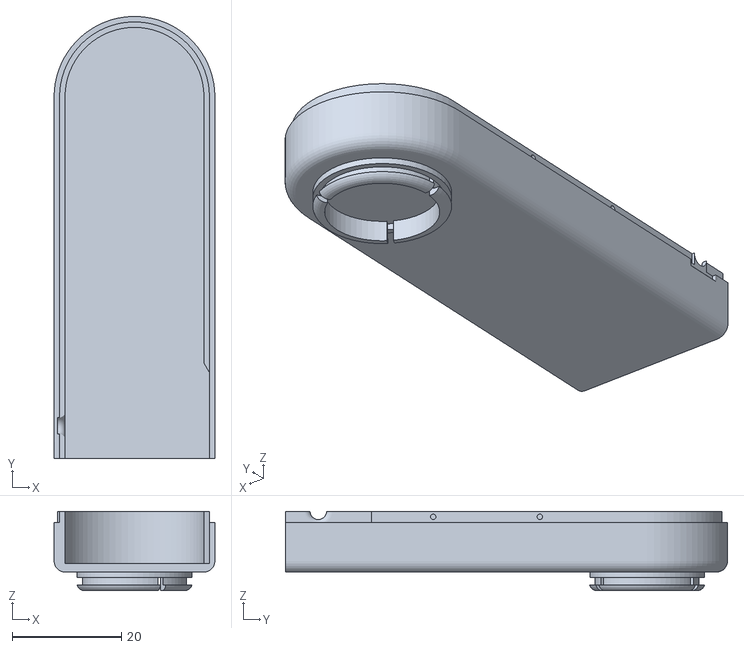
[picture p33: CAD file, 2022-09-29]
PassChain_Design 3D/Enclosure-bottom.stl
29.4 x 80.8 x 14.5

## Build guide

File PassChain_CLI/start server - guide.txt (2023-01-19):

-------------------------------------
Kill open port

sudo ss -ltpn
sudo kill -9 `sudo lsof -t -i:11111`
-------------------------------------

-----------------------------------
start server

[On Unix or MacOS, using the bash shell]: "source /path/to/venv/bin/activate"
[On Windows using the Command Prompt]: "path\to\venv\Scripts\activate.bat"

Then lunch: "python main.py"

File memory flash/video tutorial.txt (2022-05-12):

https://www.youtube.com/watch?v=TL72xHdjr9A&ab_channel=FattelodaSolo

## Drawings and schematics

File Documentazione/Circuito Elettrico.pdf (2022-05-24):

## C-Nd

÷

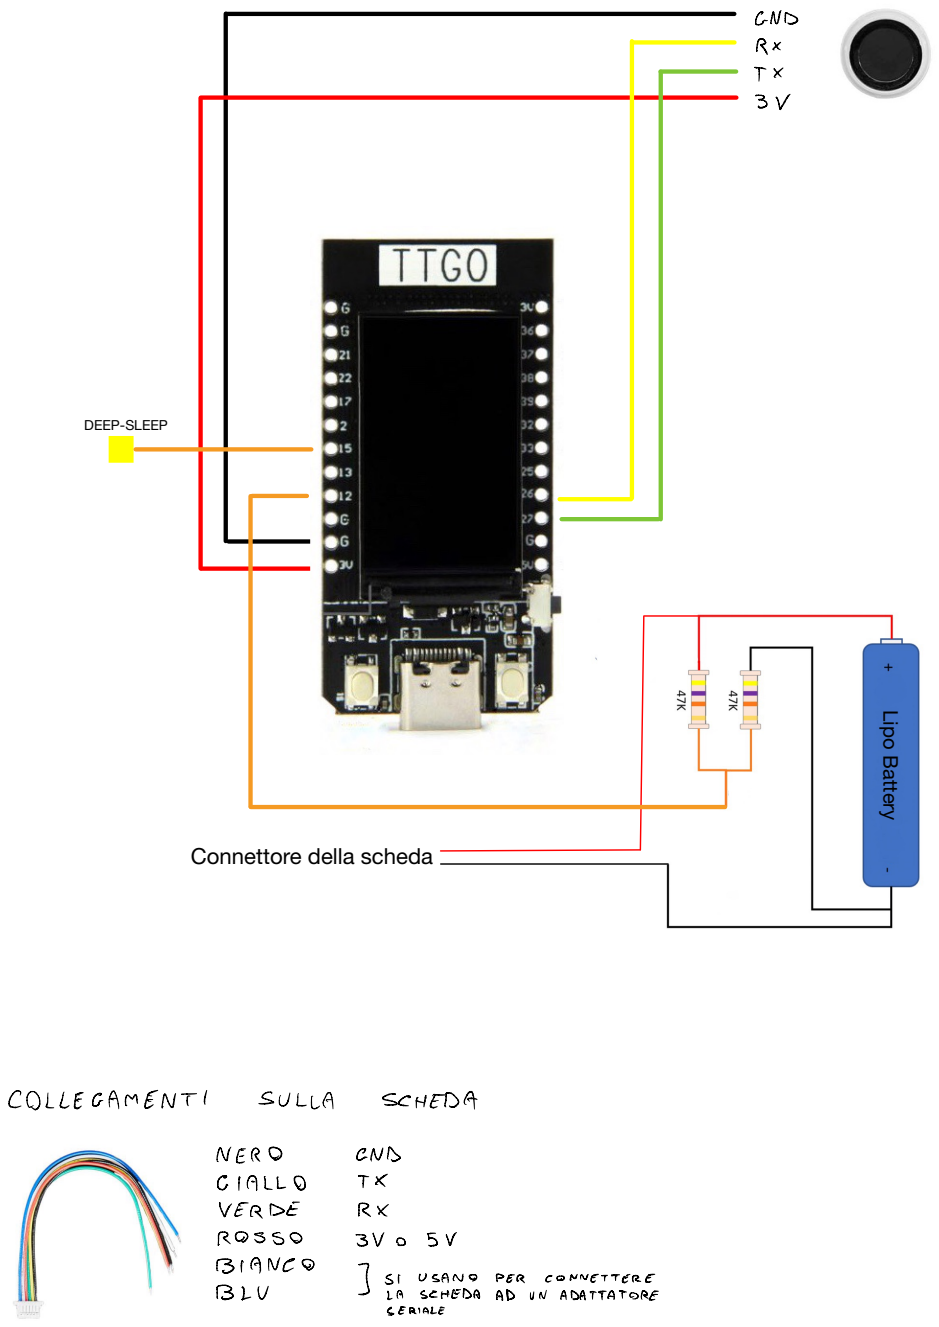
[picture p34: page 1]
DEEP-SLEEP; Lipo Battery; COLLEGAMENTI; SULLA; SCHEDA; NERO; CND; GIALLO; VERDE; ROSSO; BIANCO; USANO; PER; CONNETTERE; BLU; ADATTATORE; SERIALE

Connettore della scheda

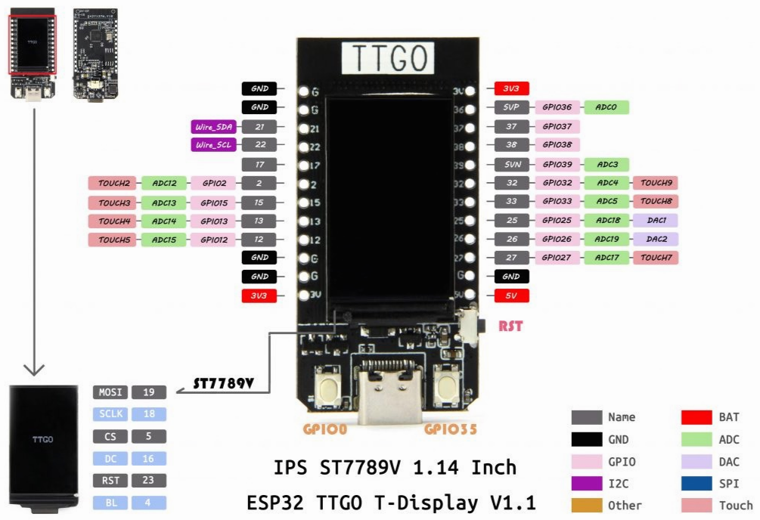
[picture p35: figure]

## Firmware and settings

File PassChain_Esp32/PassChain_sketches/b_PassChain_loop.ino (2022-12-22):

void loop(){
  buttonState1 = digitalRead(BUTTON1PIN);
  buttonState2 = digitalRead(BUTTON2PIN);

 /************************
  * menu_module loop *
  ************************/
  int menu = mainMenu();
  tft.fillRect(0,25,240,110,TFT_BLACK);

  switch(menu){
    case 0:{
      credentialsMenu();
      break;
    }

    case 1:{
      break;
    }

    case 2:{
      break;
    }

    case 3:{
      tft.fillRect(0,25,240,110,TFT_BLACK);
      accessPoint_start();
      break;
    }
  }
}

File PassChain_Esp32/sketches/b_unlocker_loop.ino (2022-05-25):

void loop(){
  buttonState1 = digitalRead(BUTTON1PIN);
  buttonState2 = digitalRead(BUTTON2PIN);
  int menu = 0;

 /************************
  * menu_module loop *
  ************************/
  menu = mainMenu();

  switch(menu){
    case 0:{
      tft.fillRect(0,25,240,110,TFT_BLACK);
      credentialMenu();
      break;
    }

    case 1:{
      break;
    }

    case 2:{
      break;
    }

    case 3:{
      break;
    }
  }
}

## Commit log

2022-03-29 Add files via upload
    Questi sono gli step da seguire per realizzare il progetto.
2022-03-30 Update ListaStepProgetto.md
    Aggiunta di un link per la risoluzione di un problema comune in fase di compilazione per le schede "esterne" come ESP32.
2022-04-04 Add files via upload
    Ho messo tutto quello che ho trovato, non è molto, e soprattutto non mi sembra di avere trovato niente di proto da utilizzare. Quindi da come ho visto dovremmo creare noi belle porzioni di codice, e il problema, è che non so effettivamente funziona su Mac e iOS. Il secondo progetto alla fine collega il dispositivo ad un'iPad, ma non fa vedere se funziona effettivamente o meno... Quindi non so. Se trovate altro, modificate questo file.
2022-04-05 Add files via upload
    Raga questo è il codice "base" da cui potete prendere spunto. In pratica fa il pairing ad un dispositivo, e una volta connesso premendo il tasto inferiore della scheda, scrive la password. Se la boar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
2022-04-10 UnlockerBoard_Doc-update
    Ho aggiunto la documentazione dei componenti hardware che utilizzeremo, e delle librerie che dovremmo usare se programmiamo la board in MicroPython, con relativa descrizione delle varie limitazioni e problematiche che comportano.
2022-04-11 Add files via upload
    Aggiunta di confronti delle librerie
2022-04-12 Add files via upload
    Aggiunta della tabella di confronto delle librerie per l'uso del fingerprint sensor. Correzione di un link sbagliato per l'uso del fingerprint sensor con Esp32.
2022-04-12 Update ListaStepProgetto.md
    Aggiunta documentazione per rimappare i pin sull'ESP32 TTGO, e sull'utilizzo del fingerprint sensor con Python.
2022-04-20 power on module
2022-04-21 Aggiunta di deep_sleep mode
    Ancora non funziona perfettamente, da revisionare(attualmente commentata in setup).
2022-04-23 block screen
    funziona, bisogna aggiustare un piccolo bug grafico
    [b_unlocker_loop.ino, blockScreen_module.ino, unlocker_sketch.ino]
2022-04-28 Update menù scroll loop, working
    Da sistemare la questione di come si ottiene la size dell'array.
2022-04-29 Images and material
2022-05-01 credentials_module
    modulo credenziali completo:
    aggiunto operazioni di scrittura, aggiornamento ed eliminazione
2022-05-04 modifica grafica testo e battery module
2022-05-05 battery migliorata
2022-05-12 memory flash
    [Configuring options.txt, prt0003_23.stl, prt0005_14(2).stl]
2022-05-25 add main menu and memory flash
    [Configuring options.txt, prt0003_23.stl, prt0005_14(2).stl]
2022-09-29 insert scroll and wifi
    [Button.stl, Enclosure-bottom.stl, Enclosure-top.stl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]
2022-12-02 add certificates
    [cert-ext-ia.cfg, cert-ext-joi.cfg, cert-ext-multiple.cfg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]
2022-12-12 ssl client & bug fix
    [cert-ext-ia.cfg, cert-ext-joi.cfg, cert-ext-multiple.cfg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]
2023-01-03 update fingerprint
